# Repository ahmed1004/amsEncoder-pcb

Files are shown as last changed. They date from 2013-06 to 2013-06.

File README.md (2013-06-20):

# AS5048B Breakout Board
## Description
This is a printed circuit board to break out the [AS5048B](http://www.ams.com/eng/Products/Magnetic-Position-Sensors/Rotary-Magnetic-Position-Sensors/AS5048B) rotary encoder to a four-pin I2C connection. This chip returns a 14-bit absolute radial position. The PCB also provides holes for two alignment pins, the CAD for which is given in AS5048B_Encoder_Board.dxf.

##Usage
### Mechanical
The AS5048B reads the absolute radial position of a diametrically polarized magnet which rotates above the center of the chip (center marked by yellow 'X' in dxf). Many magnet configurations can be used, we have found success with a 3mm diameter N52 magnet positioned 2mm away from the die surface of the chip. More detailed application notes are available in the [datasheet](http://www.ams.com/eng/content/download/250006/975176/143016)
### Electronics
The board needs to be populated with the AS5048B, as well as a 10μF 603 surface mount capacitor. There are pads for *SDA* *SCL* *Vcc* and *GND* on the top and bottom of the PCB, for daisy-chaining several boards together. There are pads on the back of the chip for mounting an optional [6-pin Molex connector](http://www.molex.com/molex/products/datasheet.jsp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)

Two solder jumpers on the back of the board set the 7-bit I2C address of the chip to be:

        0b10000 A2 A1

Where A1 and A2 are the logical values of the solder-bridged jumpers.
###Code
ams-enc in [imageproc-lib](https://github.com/biomimetics/imageproc-lib) is example code to communicate with the chip. This code uses a blocking read, which is a bit of a faux-pas in a real time loop. For an example of an asynchronous update, see a different version of ams-enc in [my repository.](https://github.com/dhaldane/imageproc-lib)

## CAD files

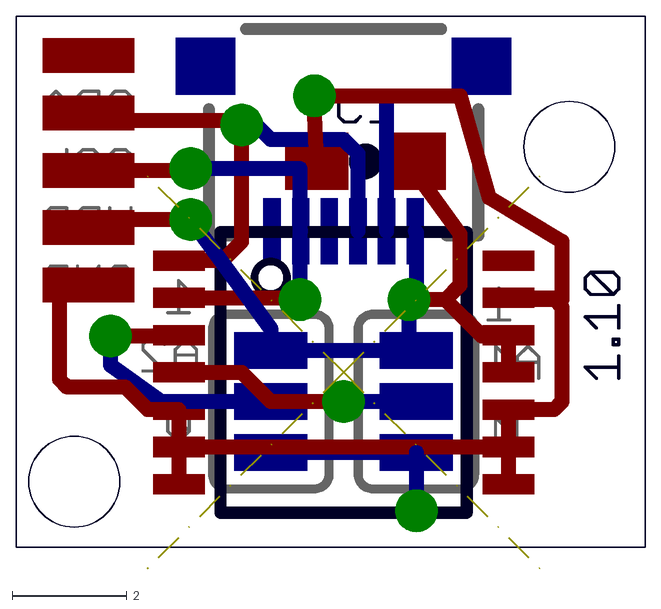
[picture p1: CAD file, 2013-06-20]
AS5048B_Encoder_board.dxf
11.0 x 9.64

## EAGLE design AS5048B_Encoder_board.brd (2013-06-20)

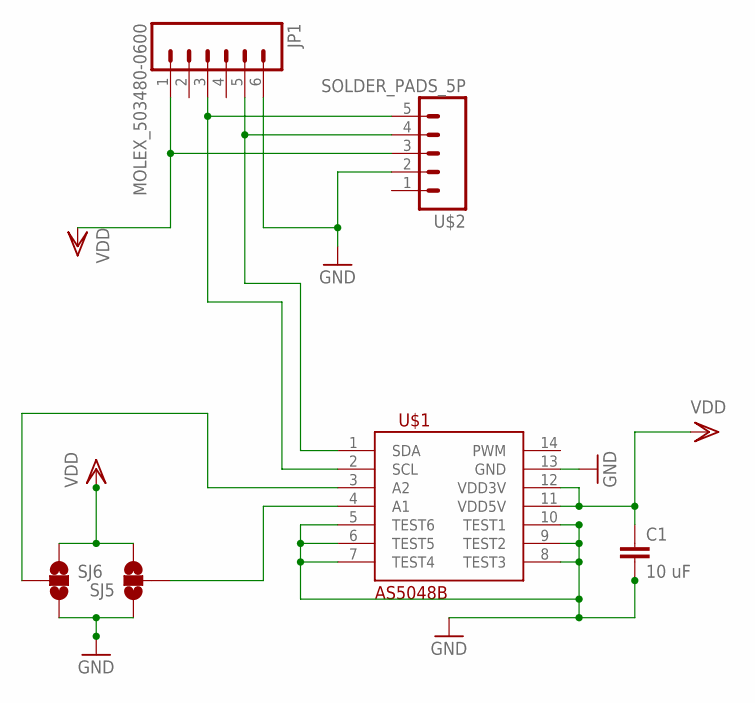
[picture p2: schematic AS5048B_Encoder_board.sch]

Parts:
C1: 10 uF; 0603-CAP
JP1: MOLEX_503480-0600
SJ5, SJ6: SOLDERJUMPER_2WAYS; SJ_3
U$1: AS5048B; TSSOP14
U$2: SOLDER_PADS_5P

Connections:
A1: SJ5.2, U$1.4 (A1)
A2: SJ6.2, U$1.3 (A2)
GND: C1.2, JP1.6, SJ5.1, SJ6.3, U$1.5 (TEST6), U$1.6 (TEST5), U$1.7 (TEST4), U$1.8 (TEST3), U$1.9 (TEST2), U$1.10 (TEST1), U$1.13 (GND), U$2.2
SCL: JP1.3, U$1.2 (SCL), U$2.5
SDA: JP1.5, U$1.1 (SDA), U$2.4
VDD: C1.1, JP1.1, SJ5.3, SJ6.1, U$1.11 (VDD5V), U$1.12 (VDD3V), U$2.3

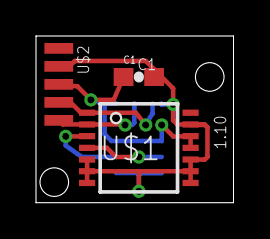
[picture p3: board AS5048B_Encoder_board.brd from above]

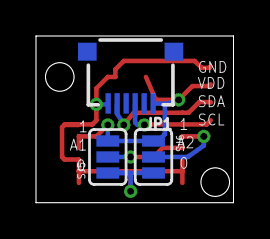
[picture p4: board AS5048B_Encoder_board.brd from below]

Board: 2 copper layers, 11.0 x 9.3 mm, 6 parts (3 on the bottom side), 6 nets.

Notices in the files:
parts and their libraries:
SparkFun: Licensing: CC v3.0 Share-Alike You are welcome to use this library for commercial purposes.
